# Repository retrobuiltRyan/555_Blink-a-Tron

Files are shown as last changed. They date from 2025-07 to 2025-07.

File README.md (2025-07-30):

# 555_Blink-a-Tron
Surface Mount device practice soldering activity.
Blink LEDS without logic using 555 timer + TLC5916 LED driver: 

Source reference TI white paper: https://www.ti.com/lit/an/slva346/slva346.pdf?ts=1731359344476&ref_url=https%253A%252F%252Fwww.google.com%252F

render front
render rear

## Bill of Materials (BOM)

| Reference | Value | Footprint | Qty | DigiKey P/N |
|---|---|---|-----|---|
| BT1 | Battery | Battery:BatteryHolder_Keystone_1058_1x2032 | 1 | BU2032SM-GCT-ND |
| C1, C2, C3 | 0.1uF | Capacitor_SMD:C_1206_3216Metric | 3 | 1292-1605-1-ND |
| C4 | 1uF | Capacitor_SMD:C_1206_3216Metric | 1 | 1276-1068-1-ND |
| D1–D8 | D | Diode_SMD:D_1206_3216Metric | 8 | 67-1359-1-ND |
| R1 | 37.4k | Resistor_SMD:R_1206_3216Metric | 1 | 311-37.4KFRCT-ND |
| R2 | 20k | Resistor_SMD:R_1206_3216Metric | 1 | 311-20.0KFRCT-ND |
| R3 | 3k – 6k | Resistor_SMD:R_1206_3216Metric | 1 | 311-6.2KERCT-ND |
| SW1 | SW_Push | Button_Switch_SMD:SW_SPST_Omron_B3FS-100xP | 1 | CKN12221-1-ND |
| U1 | ICM7555xB | Package_SO:SOIC-8_3.9x4.9mm_P1.27mm | 1 | 296-1336-1-ND |
| U2 | TLC5916 | Package_SO:SOIC-16_3.9x9.9mm_P1.27mm | 1 | 296-22710-1-ND |

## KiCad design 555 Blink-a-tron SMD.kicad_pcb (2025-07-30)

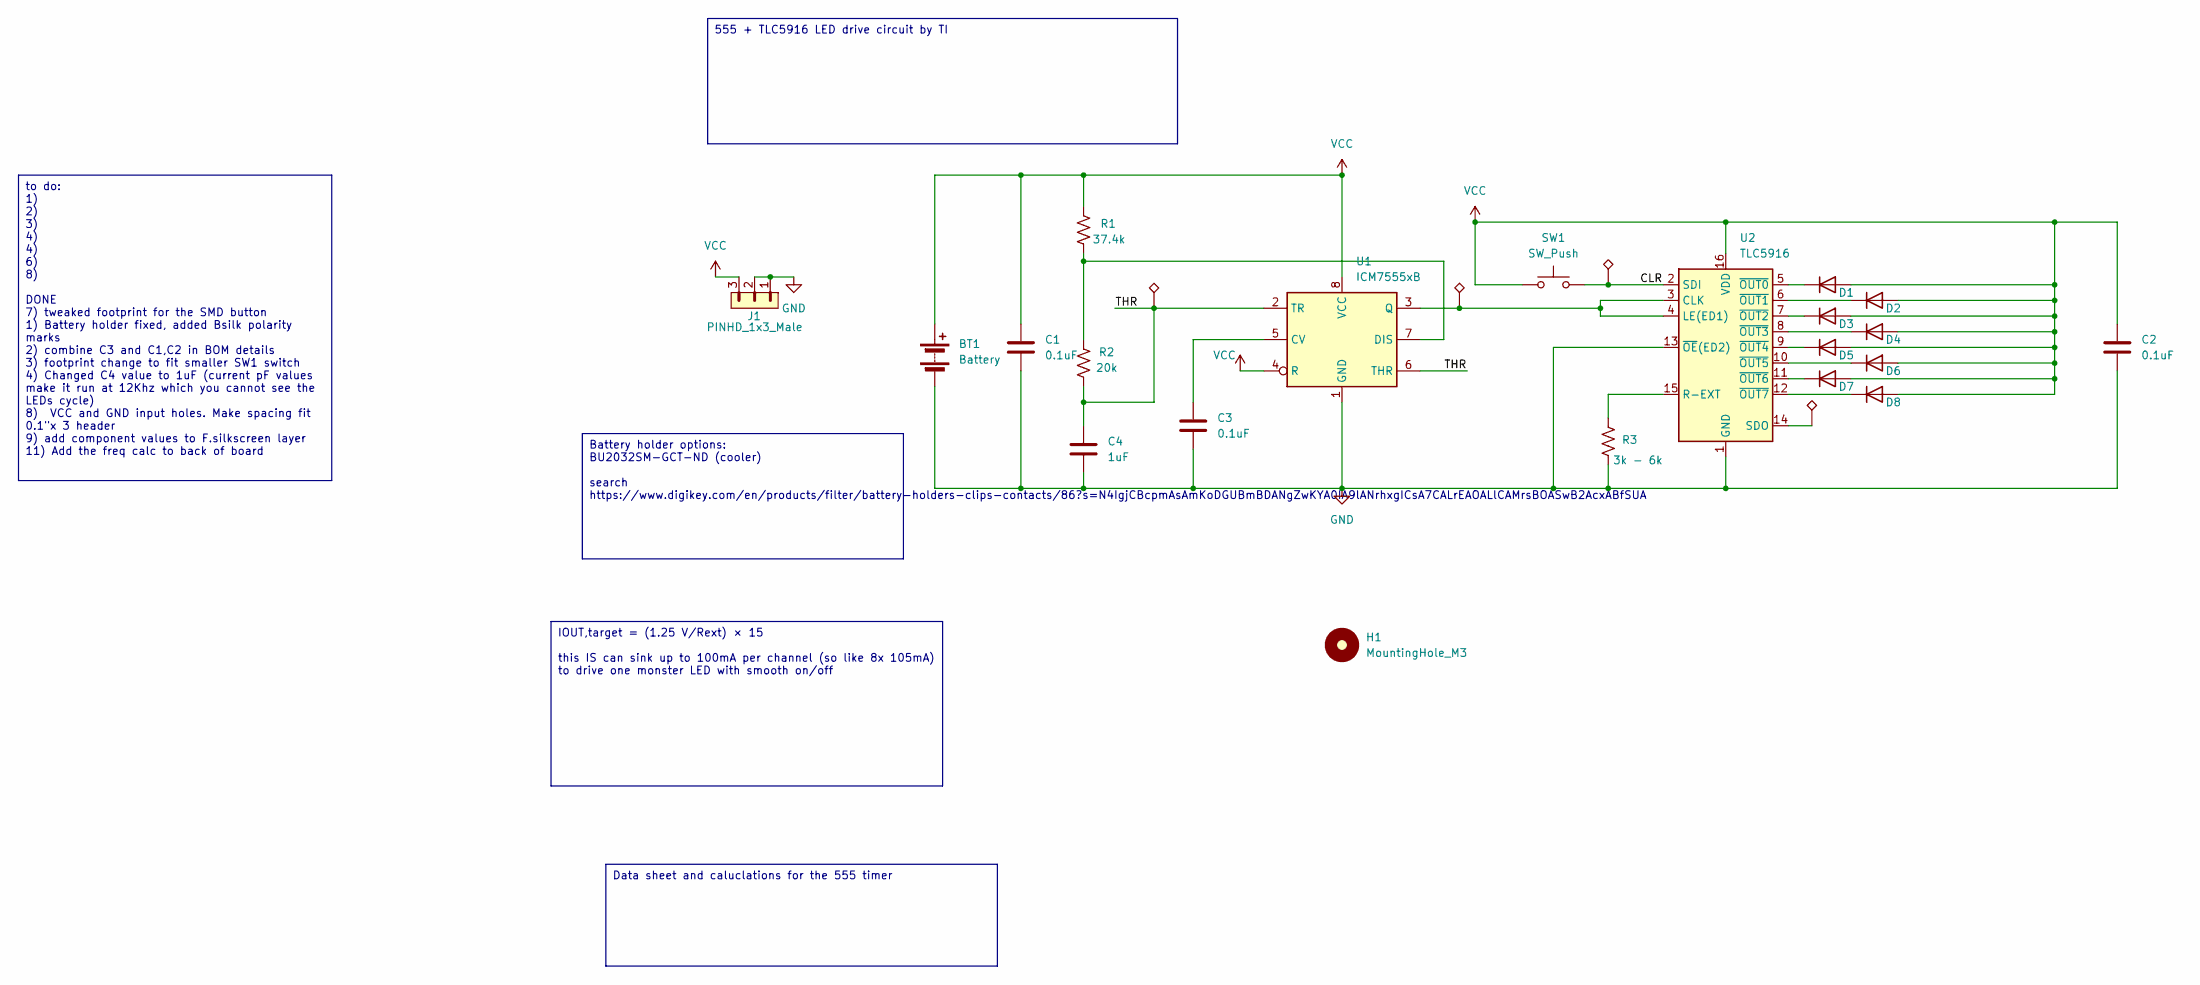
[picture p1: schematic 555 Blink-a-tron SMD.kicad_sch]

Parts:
BT1: Battery; BatteryHolder_Keystone_1058_1x2032; DigiKey P/N BU2032SM-GCT-ND
C1, C2, C3: 0.1uF; C_1206_3216Metric; DigiKey P/N 1292-1605-1-ND
C4: 1uF; C_1206_3216Metric; DigiKey P/N 1276-1068-1-ND
CLK1, CLK2: TestPoint_Alt; TestPoint_THTPad_1.5x1.5mm_Drill0.7mm
D1, D2, D3, D4, D5, D6, D7, D8: D; D_1206_3216Metric; DigiKey P/N 67-1359-1-ND
H1: MountingHole_M3; MountingHole_3.2mm_M3
J1: PINHD_1x3_Male; PinHeader_1x03_P2.54mm_Vertical
R1: 37.4k; R_1206_3216Metric; DigiKey P/N 311-37.4KFRCT-ND
R2: 20k; R_1206_3216Metric; DigiKey P/N 311-20.0KFRCT-ND
R3: 3k - 6k; R_1206_3216Metric; DigiKey P/N 311-6.2KERCT-ND
SDO1: TestPoint_Alt; TestPoint_THTPad_1.5x1.5mm_Drill0.7mm
SW1: SW_Push; SW_SPST_Omron_B3FS-100xP; DigiKey P/N CKN12221-1-ND
THR1: TestPoint_Alt; TestPoint_THTPad_1.5x1.5mm_Drill0.7mm
U1: ICM7555xB; SOIC-8_3.9x4.9mm_P1.27mm; DigiKey P/N 296-1336-1-ND
U2: TLC5916; SOIC-16_3.9x9.9mm_P1.27mm; DigiKey P/N 296-22710-1-ND

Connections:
/CLR: CLK2.1, SW1.2, U2.2 (SDI); also elsewhere on the board
/THR: C4.1, R2.1, THR1.1, U1.2 (TR), U1.6 (THR)
GND: BT1.2 (-), C1.2, C2.2, C3.2, C4.2, J1.1, J1.2, R3.1, U1.1 (GND), U2.1 (GND), U2.13 (~OE(ED2))
unnamed: D1.1 (K), U2.5 (~OUT0)
unnamed: D2.1 (K), U2.6 (~OUT1)
unnamed: D3.1 (K), U2.7 (~OUT2)
unnamed: D4.1 (K), U2.8 (~OUT3)
unnamed: D5.1 (K), U2.9 (~OUT4)
unnamed: D6.1 (K), U2.10 (~OUT5)
unnamed: D7.1 (K), U2.11 (~OUT6)
unnamed: D8.1 (K), U2.12 (~OUT7)
unnamed: C3.1, U1.5 (CV)
unnamed: R1.1, R2.2, U1.7 (DIS)
unnamed: CLK1.1, U1.3 (Q), U2.3 (CLK), U2.4 (LE(ED1))
unnamed: R3.2, U2.15 (R-EXT)
unnamed: SDO1.1, U2.14 (SDO)
VCC: BT1.1 (+), C1.1, C2.1, D1.2 (A), D2.2 (A), D3.2 (A), D4.2 (A), D5.2 (A), D6.2 (A), D7.2 (A), D8.2 (A), J1.3, R1.2, SW1.1, U1.4 (R), U1.8 (VCC), U2.16 (VDD)

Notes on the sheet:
Battery holder options: BU2032SM-GCT-ND (cooler) search https://www.digikey.com/en/products/filter/battery-holders-clips-contacts/86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
555 + TLC5916 LED drive circuit by TI
Data sheet and caluclations for the 555 timer
IOUT,target = (1.25 V/Rext) × 15 this IS can sink up to 100mA per channel (so like 8x 105mA) to drive one monster LED with smooth on/off
to do: 1) 2) 3) 4) 4) 6) 8) DONE 7) tweaked footprint for the SMD button 1) Battery holder fixed, added Bsilk polarity marks 2) combine C3 and C1,C2 in BOM details 3) footprint change to fit smaller SW1 switch 4) Changed C4 value to 1uF (current pF values make it run at 12Khz which you cannot see t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

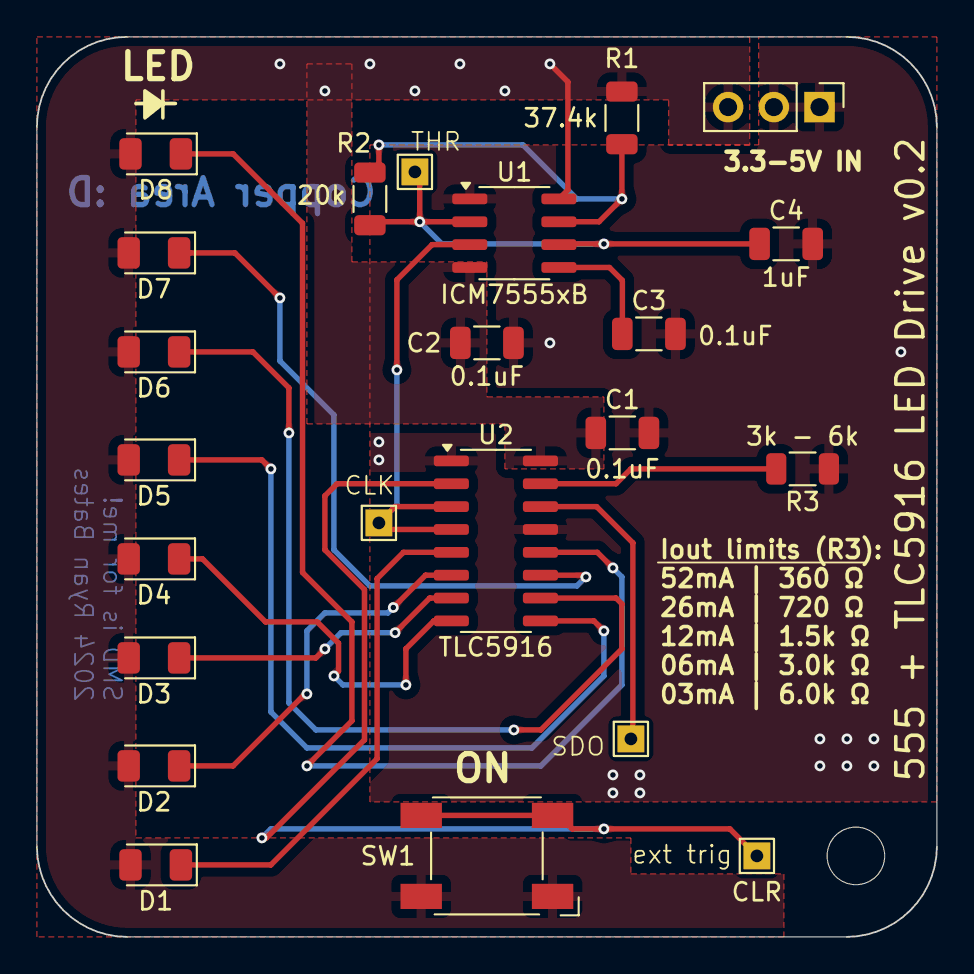
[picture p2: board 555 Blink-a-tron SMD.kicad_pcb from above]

Board: 2 copper layers, 50.0 x 50.0 mm, 25 parts (1 on the bottom side), 17 nets.

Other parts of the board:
CLR: TestPoint_Alt; TestPoint_THTPad_1.5x1.5mm_Drill0.7mm

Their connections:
/CLR: CLR.1; also elsewhere on the board

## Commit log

2025-07-30 PCB design files (kiCAD)
    [555 Blink-a-tron SMD.kicad_pcb, 555 Blink-a-tron SMD.kicad_sch]
2025-07-30 Gerbers
    JLCPCB
    [555 Blink-a-tron SMD-B_Cu.gbl, 555 Blink-a-tron SMD-B_Mask.gbs, 555 Blink-a-tron SMD-B_Paste.gbp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]
